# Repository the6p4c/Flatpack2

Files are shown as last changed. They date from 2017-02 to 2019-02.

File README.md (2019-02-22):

# Flatpack2
Software, hardware and protocol information for the Eltek Flatpack2.

Provided is [a simple voltage changing Arduino sketch](Arduino/fp2_set_voltage/).

Check [Protocol.md](https://github.com/The6P4C/Flatpack2/blob/master/Protocol.md) for information about the CAN bus protocol used by the Flatpack2.

# Transceiver + Breakout Board
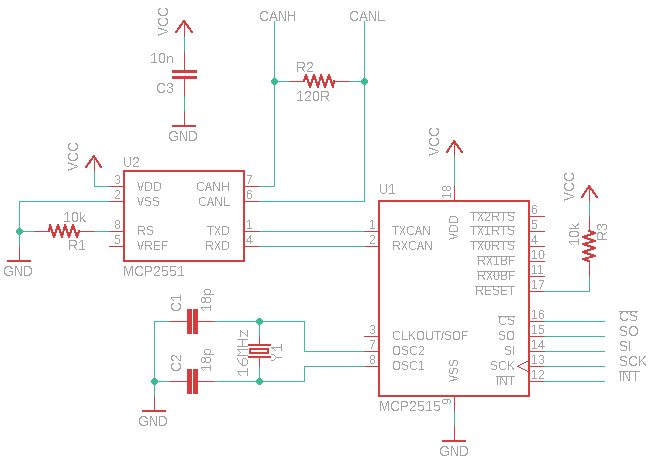
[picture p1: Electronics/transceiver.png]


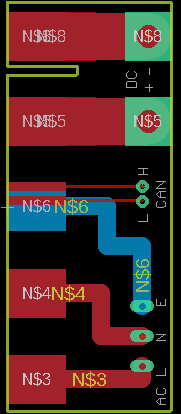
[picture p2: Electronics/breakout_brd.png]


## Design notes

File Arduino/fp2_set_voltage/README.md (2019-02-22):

# How to use
You'll need the following library (simply install it like any other Arduino library):  
https://github.com/coryjfowler/MCP_CAN_lib

Then, download this sketch. You'll have to modify the `#define VOLTAGE ...` line to indicate what voltage you require. This value is in centivolts, so you'll have to convert your desired voltage into that unit. For example, if you want the supply to output 47.13 V, change the line to `#define VOLTAGE 4713`.

You may also have to change the `const int CAN_CS_PIN = ...;` and `const int CAN_INT_PIN = ...;` lines to match how your transceiver is wired up. If you're using the transceiver as specified in this repository, you won't need to change anything here.

If your transceiver doesn't use a MCP2515, then you might have to rewrite some of the sketch to interface correctly. The specifics of the protocol are in [this](https://github.com/The6P4C/Flatpack2/tree/master/Protocol.md) file and how they're used should hopefully be pretty clear by reading the sketch.

# Changing the voltage
After the supply is connected to your Arduino (CAN bus and common ground), you should simply be able to turn on the PSU, upload the sketch to your Arduino, and open the serial monitor to check the process is running smoothly. You should see the messages "Entering Configuration Mode Successful!", "Setting Baudrate Successful!" and "MCP2515 initialized successfully.". After a moment, the message "Starting set" will appear. Your screen will probably fill with messages that look similar to (but not exactly like) this: "ID: 0x05014004 Length: 8 Data: 0x17 0x00 0x00 0xD1 0x12 0xEE 0x00 0x17". After a while, the stream of messages will slow down to one message around every 3-4 seconds.

When this happens, turn off the power supply's AC power, and disconnect the USB, then the CAN bus connection, then disconnect the common ground. Give the supply about 2 minutes to properly shut down and drain its internal caps, then reconnect only the AC power and measure the DC output voltage. It should, with luck, measure as the voltage you set.

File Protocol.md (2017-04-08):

<!--
<table>
	<tr>
		<td><b>Byte</b></td> <td>0</td> <td>1</td> <td>2</td> <td>3</td> <td>4</td> <td>5</td> <td>6</td> <td>7</td>
	</tr>
	<tr>
		<td><b>Value</b></td> <td>Byte 0</td> <td>Byte 1</td> <td>Byte 2</td> <td>Byte 3</td> <td>Byte 4</td> <td>Byte 5</td> <td>Byte 6</td> <td>Byte 7</td>
	</tr>
</table>
-->

# Conventions in This Document
RX is a message from the power supply to the transceiver  
TX is a message from the transceiver to the power supply

# Hardware
The Flatpack2's CAN bus runs at 125kbit/s, using an extended ID field. The bus is relative to the PSU's negative output rail. Failure to connect the negative of the supply with the ground of your CAN transceiver will likely blow the transceiver up (this took me 3 MCP2551s to realize).

# Messages
## (TX) Log in, `0x050048XX`
Sent to log into a power supply. Unknown if address is a broadcast or a specific message to a single power supply. After approximately 15 seconds, the power supply will log out again if it does not recieve another log in message.

The ID of the supply is set by the last byte of the address, where `XX = ID * 4`. The ID ranges from `0x01` to `0x3F` (resulting in a range for `XX` of `0x04` to `0xFC`).

<table>
	<tr>
		<td><b>Byte</b></td> <td>0</td> <td>1</td> <td>2</td> <td>3</td> <td>4</td> <td>5</td> <td>6</td> <td>7</td>
	</tr>
	<tr>
		<td><b>Value</b></td> <td colspan='6'>Power supply's serial number</td> <td><code>0x00</code></td> <td><code>0x00</code></td>
	</tr>
</table>

## (RX) CAN bus introduction (??), `0x0500XXXX`
Sent approximately every two seconds. `XXXX` are usually the last four digits of the power supply's serial number. (Doesn't always exactly match - supply ending with 5418 sends 1418)

<table>
	<tr>
		<td><b>Byte</b></td> <td>0</td> <td>1</td> <td>2</td> <td>3</td> <td>4</td> <td>5</td> <td>6</td> <td>7</td>
	</tr>
	<tr>
    	<td><b>Value</b></td> <td><code>0x1B</code></td> <td colspan='6'>Power supply's serial number</td> <td><code>0x00</code></td>
	</tr>
</table>

## (RX) Status, `0x05XX40YY`
Sent by the power supply after it is logged into, and contains information about the current state of the power supply.

`XX` is the power supply's ID.

| Value of `YY` | Power supply state |
| --- | --- |
| `0x04` | Normal operation |
| `0x08` | Warning |
| `0x0C` | Alarm |
| `0x10` | Walk in (voltage ramping up) |

Current, output voltage and input voltage are stored in little endian (LSB first). All temperatures are in degrees Celsius. Current is in deciamps (i.e. 21.2A is 212). Output voltage is in centivolts (i.e. 48.52V is 4852). Input voltage is in volts.

<table>
	<tr>
		<td><b>Byte</b></td> <td>0</td> <td>1</td> <td>2</td> <td>3</td> <td>4</td> <td>5</td> <td>6</td> <td>7</td>
	</tr>
	<tr>
		<td><b>Value</b></td> <td>Intake temperature</td> <td colspan='2'>Current</td> <td colspan='2'>Output voltage</td> <td colspan='2'>Input voltage</td> <td>Output temperature</td>
	</tr>
</table>

## (RX) Log in request (??), `0x05XX4400`
Sent approximately every 15 seconds. Seems to be the power supply introducing itself to the CAN bus network.

`XX` is the power supply's ID.

<table>
	<tr>
		<td><b>Byte</b></td> <td>0</td> <td>1</td> <td>2</td> <td>3</td> <td>4</td> <td>5</td> <td>6</td> <td>7</td>
	</tr>
	<tr>
		<td><b>Value</b></td> <td colspan='6'>Power supply's serial number</td> <td><code>0x00</code></td> <td><code>0x00</code></td>
	</tr>
</table>

## (TX) Set default voltage, `0x05XX9C00`
Sent to the power supply to set its default voltage. Does not take effect until the supply is logged out. If the supply is logged in when the command is sent, the voltage is set when the log in times out. If it is not logged in, the voltage will be set when the supply logs in then times out.

`XX` is the power supply's ID.

The voltage is stored in little-endian and is in centivolts (i.e. 48.52V is 4852).

<table>
	<tr>
		<td><b>Byte</b></td> <td>0</td> <td>1</td> <td>2</td> <td>3</td> <td>4</td>
	</tr>
	<tr>
		<td><b>Value</b></td> <td><code>0x29</code></td> <td><code>0x15</code></td> <td><code>0x00</code></td> <td colspan='2'>New voltage</td>
	</tr>
</table>

## (TX) Alarms/warnings information request, `0x05XXBFFC`
Sent to the power supply to request information on the current warnings and alarms. Should be sent after recieving an `0x05XX40YY` message where `YY = 08` or `YY = 0C` (i.e a warning or alarm is present). Byte 2 determines if warning or alarm information is returned.

<table>
	<tr>
		<td><b>Byte</b></td> <td>0</td> <td>1</td> <td>2</td>
	</tr>
	<tr>
		<td><b>Value</b></td> <td><code>0x08</code></td> <td><code>0x04</code> (warnings), <code>0x08</code> (alarms)</td> <td><code>0x00</code></td>
	</tr>
</table>

## (RX) Alarms/warnings information, `0x05XXBFFC`
Sent by the power supply in response to recieving an `0x05XXBFFC` message. Contains information about any alarms or warnings present, depending on the contents of the request message.

`XX` is the power supply's ID.

<table>
	<tr>
		<td><b>Byte</b></td> <td>0</td> <td>1</td> <td>2</td> <td>3</td> <td>4</td> <td>5</td> <td>6</td>
	</tr>
	<tr>
		<td><b>Value</b></td> <td><code>0x0E</code></td> <td><code>0x04</code> (warnings), <code>0x08</code> (alarms)</td> <td><code>0x00</code></td> <td>Warning/alarm bit field byte 1</td> <td>Warning/alarm bit field byte 2</td> <td><code>0x00</code></td> <td><code>0x00</code></td>
	</tr>
</table>

### Warnings/Alarms
Bit 0 is the LSB.

| Bit | Warning/alarm bit field byte 1 | Warning/alarm bit field 2 |
| --- | --- | --- |
| 0 | OVS Lock Out | Internal Voltage |
| 1 | Mod Fail Primary | Module Fail |
| 2 | Mod Fail Secondary | Mod Fail Secondary |
| 3 | High Mains | Fan 1 Speed Low |
| 4 | Low Mains | Fan 2 Speed Low |
| 5 | High Temp | Sub Mod1 Fail |
| 6 | Low Temp | Fan 3 Speed Low |
| 7 | Current Limit | Inner Volt |

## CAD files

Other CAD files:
Electronics/Edge Connector/Edge Connector.dxf

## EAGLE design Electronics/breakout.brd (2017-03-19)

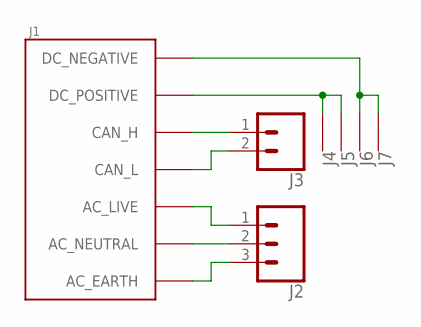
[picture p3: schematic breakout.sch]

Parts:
J1: FLATPACK2_CON
J2: WEIDMULLER_PM_508
J3: CONN_021X02_NO_SILK; 1X02_NO_SILK
J4, J5, J6, J7: FLATPACK2_DC_LUG

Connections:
unnamed: J1.CAN_H_TOP (CAN_H), J3.1
unnamed: J1.CAN_L_TOP (CAN_L), J3.2
unnamed: J1.AC_LIVE_BOTTOM (AC_LIVE), J1.AC_LIVE_TOP (AC_LIVE), J2.1
unnamed: J1.AC_NEUTRAL_BOTTOM (AC_NEUTRAL), J1.AC_NEUTRAL_TOP (AC_NEUTRAL), J2.2
unnamed: J1.DC_POSITIVE_BOTTOM (DC_POSITIVE), J1.DC_POSITIVE_TOP (DC_POSITIVE), J4.P$1, J5.P$1
unnamed: J1.AC_EARTH, J2.3
unnamed: J1.DC_NEGATIVE_BOTTOM (DC_NEGATIVE), J1.DC_NEGATIVE_TOP (DC_NEGATIVE), J6.P$1, J7.P$1

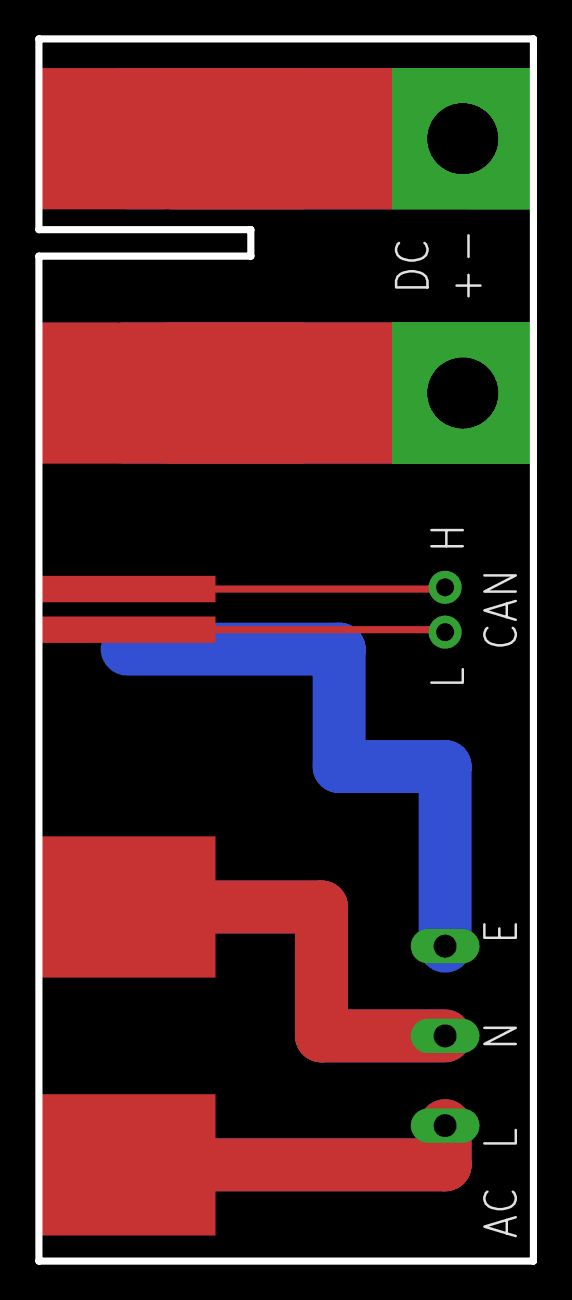
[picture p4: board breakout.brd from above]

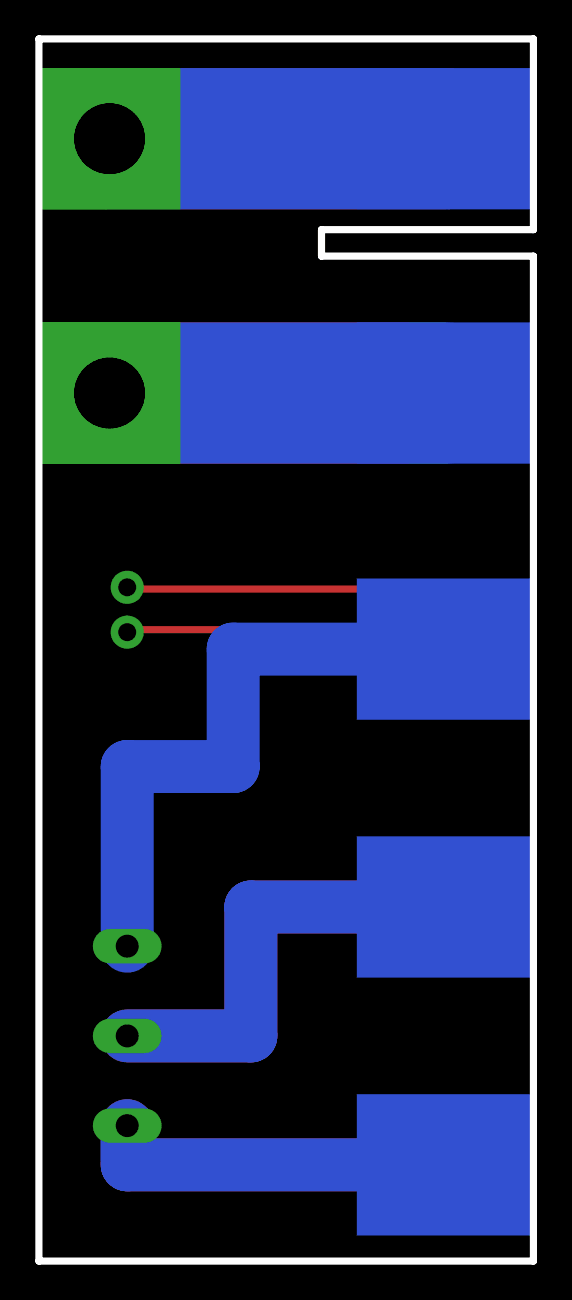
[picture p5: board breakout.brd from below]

Board: 2 copper layers, 28.0 x 69.2 mm, 7 parts (2 on the bottom side), 7 nets.

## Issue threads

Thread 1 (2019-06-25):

Can you set a constant current?

jutshanahan, 2019-06-25:

The6P4C, 2019-06-27:
I'm not 100% sure about that, sorry. There's definitely more to the protocol than I have here, since I know for sure there's commands to adjust the voltage instantaneously (without a log out/in required) but I haven't found them yet. I wouldn't be surprised if there was a CC mode - I just don't know about it!

Closed 2019-07-14.

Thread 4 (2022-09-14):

Set default doesn't stick

IonCaza, 2022-09-14:
Hey there, I have a flatpack2 (non-HE) 48v/2000.

I'm able to send a login message to 0x05004804 with the serial number successfully. After login, for 5 seconds I see messages come from 05014004 with status.

I'm also able to send messages to 0x05019C00 with data (0x29, 0x15, 0x00, 0xC0, 0x12) and 0x05FF4004 (or 0x05FF4005) with data (0x2C, 0x01, 0xC0, 0x12, 0xC0, 0x12, 0x24, 0x13) to set voltage to 48V. For 5 seconds, the voltage sticks to 48V but it returns to 53.5V after that. I send all messages together, login, set default, and set voltage.

I can't get it to stick to 48V however... any idea why? Thank you for your help.

moeterich, 2022-11-11:
Will sending to 05009C00 fix it for you ?

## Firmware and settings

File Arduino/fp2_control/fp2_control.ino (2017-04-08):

#include <mcp_can.h>
#include <SPI.h>

const int CAN_CS_PIN = 10;
const int CAN_INT_PIN = 2;

const char *alarms0Strings[] = {"OVS_LOCK_OUT", "MOD_FAIL_PRIMARY", "MOD_FAIL_SECONDARY", "HIGH_MAINS", "LOW_MAINS", "HIGH_TEMP", "LOW_TEMP", "CURRENT_LIMIT"};
const char *alarms1Strings[] = {"INTERNAL_VOLTAGE", "MODULE_FAIL", "MOD_FAIL_SECONDARY", "FAN1_SPEED_LOW", "FAN2_SPEED_LOW", "SUB_MOD1_FAIL", "FAN3_SPEED_LOW", "INNER_VOLT"};

MCP_CAN CAN(CAN_CS_PIN);

bool serialNumberReceived = false;
uint8_t serialNumber[6];

unsigned long lastLogInTime = 0;

void setup() {
	Serial.begin(115200);

	pinMode(CAN_CS_PIN, OUTPUT);
	pinMode(CAN_INT_PIN, INPUT);

	if (CAN.begin(MCP_ANY, CAN_125KBPS, MCP_16MHZ) == CAN_OK) {
		Serial.println("MCP2515 initialized successfully.");
	} else {
		Serial.println("Failed to initialize MCP2515. Halting.");
		while(1);
	}

	CAN.setMode(MCP_NORMAL);
}

void printMessage(uint32_t rxID, uint8_t len, uint8_t rxBuf[]) {
	char output[256];

	snprintf(output, 256, "ID: 0x%.8lX Length: %1d Data:", rxID, len);
	Serial.print(output);

	for (int i = 0; i < len; ++i) {
		snprintf(output, 256, " 0x%.2X", rxBuf[i]);
		Serial.print(output);
	}

	Serial.println();
}

void logIn() {
	Serial.println("--------");
	Serial.println("Logging in.");
	Serial.println("--------");

	uint8_t txBuf[8] = { 0 };

	for (int i = 0; i < 6; ++i) {
		txBuf[i] = serialNumber[i];
	}

	CAN.sendMsgBuf(0x05004804, 1, 8, txBuf);
}

void processLogInRequest(uint32_t rxID, uint8_t len, uint8_t rxBuf[]) {
	Serial.println("--------");
	Serial.print("Found power supply ");

	char output[3];

	for (int i = 0; i < 6; ++i) {
		serialNumber[i] = rxBuf[i + 1];

		snprintf(output, 3, "%.2X", serialNumber[i]);
		Serial.print(output);
	}

	serialNumberReceived = true;

	Serial.println();
	Serial.println("--------");
}

void processStatusMessage(uint32_t rxID, uint8_t len, uint8_t rxBuf[]) {
	int intakeTemperature = rxBuf[0];
	float current = 0.1f * (rxBuf[1] | (rxBuf[2] << 8));
	float outputVoltage = 0.01f * (rxBuf[3] | (rxBuf[4] << 8));
	int inputVoltage = rxBuf[5] | (rxBuf[6] << 8);
	int outputTemperature = rxBuf[7];

	char output[256];
	
	Serial.println("--------");
	Serial.println("Status message:");

	Serial.print("Intake temperature: ");
	Serial.print(intakeTemperature);
	Serial.println(" deg C");

	Serial.print("Current: ");
	Serial.print(current);
	Serial.println("A");

	Serial.print("Output voltage: ");
	Serial.print(outputVoltage);
	Serial.println("V");

	Serial.print("Input voltage: ");
	Serial.print(inputVoltage);
	Serial.println("V");

	Serial.print("Output temperature: ");
	Serial.print(outputTemperature);
	Serial.println(" deg C");

	if (rxID == 0x05014010) {
		Serial.println("Currently in walk in (voltage ramping up)");
	}

	bool hasWarning = rxID == 0x05014008;
	bool hasAlarm = rxID == 0x0501400C;

	if (hasWarning) {
		Serial.println("WARNING");
	} else if (hasAlarm) {
		Serial.println("ALARM");
	}

	if (hasWarning || hasAlarm) {
		uint8_t txBuf[3] = {0x08, hasWarning ? 0x04 : 0x08, 0x00};
		CAN.sendMsgBuf(0x0501BFFC, 1, 3, txBuf);
	}

	Serial.println("--------");
}

void processWarningOrAlarmMessage(uint32_t rxID, uint8_t len, uint8_t rxBuf[]) {
	bool isWarning = rxBuf[1] == 0x04;

	Serial.println("--------");
	if (isWarning) {
		Serial.print("Warnings:");
	} else {
		Serial.print("Alarms:");
	}

	uint8_t alarms0 = rxBuf[3];
	uint8_t alarms1 = rxBuf[4];

	for (int i = 0; i < 8; ++i) {
		if (alarms0 & (1 << i)) {
			Serial.print(" ");
			Serial.print(alarms0Strings[i]);
		}

		if (alarms1 & (1 << i)) {
			Serial.print(" ");
			Serial.print(alarms1Strings[i]);
		}
	}

	Serial.println();
	Serial.println("--------");;
}

void loop() {
	// Log in every second
	if (serialNumberReceived && millis() - lastLogInTime > 1000) {
		logIn();

		lastLogInTime = millis();
	}

	// Active low
	if (!digitalRead(CAN_INT_PIN)) {
		uint32_t rxID;
		uint8_t len = 0;
		uint8_t rxBuf[8];

		CAN.readMsgBuf((unsigned long *)&rxID, &len, rxBuf);

		// Limit ID to lowest 29 bits (extended CAN)
		rxID &= 0x1FFFFFFF;

		printMessage(rxID, len, rxBuf);

		if (!serialNumberReceived && (rxID & 0xFFFF0000) == 0x05000000) {
			processLogInRequest(rxID, len, rxBuf);
		} else if ((rxID & 0xFFFFFF00) == 0x05014000) {
			processStatusMessage(rxID, len, rxBuf);
		} else if (rxID == 0x0501BFFC) {
			processWarningOrAlarmMessage(rxID, len, rxBuf);
		}
	}
}

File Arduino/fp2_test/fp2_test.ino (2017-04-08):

#include <mcp_can.h>
#include <SPI.h>

const int CAN_CS_PIN = 10;
const int CAN_INT_PIN = 2;

MCP_CAN CAN(CAN_CS_PIN);

void setup() {
	Serial.begin(115200);

	pinMode(CAN_CS_PIN, OUTPUT);
	pinMode(CAN_INT_PIN, INPUT);

	if (CAN.begin(MCP_ANY, CAN_125KBPS, MCP_16MHZ) == CAN_OK) {
		Serial.println("MCP2515 initialized successfully.");
	} else {
		Serial.println("Failed to initialize MCP2515. Halting.");
		while(1);
	}

	CAN.setMode(MCP_NORMAL);
}

void printMessage(char *direction, long unsigned int id, unsigned char len, unsigned char buf[]) {
	char output[256];

	snprintf(output, 256, "%s ID: 0x%.8lX Length: %1d Data:", direction, id, len);
	Serial.print(output);

	for (int i = 0; i < len; ++i) {
		snprintf(output, 256, " 0x%.2X", buf[i]);
		Serial.print(output);
	}

	Serial.print(" ");

	for (int i = 0; i < len; ++i) {
		if (buf[i] >= 0x20 && buf[i] <= 0x7E) {
			Serial.print((char) buf[i]);
		} else {
			Serial.print(" ");
		}
	}

	Serial.println();
}

void loop() {
	while (Serial.available()) {
		// IDIDIDID NB DD DD DD DD DD DD DD DD

		String s = Serial.readString();

		long unsigned int txID = strtol(s.substring(0, 8).c_str(), nullptr, 16);
		unsigned char len = strtol(s.substring(9, 10).c_str(), nullptr, 10);
		unsigned char txBuf[8] = {0};

		Serial.println();

		for (int i = 0; i < len; ++i) {
			txBuf[i] = strtol(s.substring(11 + i * 3, 14 + i * 3).c_str(), nullptr, 16);
		}

		CAN.sendMsgBuf(txID, 1, len, txBuf);
		
		printMessage("TX", txID, len, txBuf);
	}

	// INT pin is active low
	if (!digitalRead(CAN_INT_PIN)) {
		long unsigned int rxID;
		unsigned char len = 0;
		unsigned char rxBuf[8];

		CAN.readMsgBuf(&rxID, &len, rxBuf);

		// Limit ID to lowest 29 bits
		rxID &= 0x1FFFFFFF;

		printMessage("RX", rxID, len, rxBuf);
	}
}

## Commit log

2017-02-11 Correct edge connector dimensions and show both sides in DXF
    [Edge Connector.dxf, edge connector.dxf]
2017-02-11 Mirror bottom in edge connector CAD model
    [Edge Connector.dxf]
2017-02-12 Formatting changes in protocol description
    [Edge Connector.dxf]
2017-02-12 Remove old Arduino code
2017-02-14 Lots of changes; final board revision
    [Edge Connector.dxf, breakout.brd, breakout.sch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]
2017-03-19 Final revision of Flatpack breakout PCB
    [breakout.brd, breakout.sch]
2017-03-26 Add voltage setting sketch
2017-04-08 Complete replacement of most files.
    [Edge Connector.dxf, transceiver.sch]
2017-04-08 Add CAN bus transceiver sketch
2017-04-08 Print ASCII in test sketch
2017-06-18 Fix merge conflict
    [transceiver.sch]
2017-09-18 Update for schematic conventions
    [transceiver.sch]
2019-02-22 Add images of breakout board and transceiver schematic

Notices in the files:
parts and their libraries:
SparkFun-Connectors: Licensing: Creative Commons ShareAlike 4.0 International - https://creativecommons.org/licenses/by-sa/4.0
